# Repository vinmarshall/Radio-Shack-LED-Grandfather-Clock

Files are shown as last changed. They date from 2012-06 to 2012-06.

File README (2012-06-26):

These files are the plans for the "Radio Shack LED Grandfather Clock" project
that was featured in the July 2012 issue of Popular Science.  Look at
the instructions file for more information.

./grandfather_clock_code - Arduino code

./mechanical - CAD files and laser cutting templates.

./parts - Bill of Materials and parts sourcing information.

./PCB - Circuit schematic and board layout in the Express PCB format.

./schematic - The schematic for the circuit.

instructions.pdf - Instructions for building this project.

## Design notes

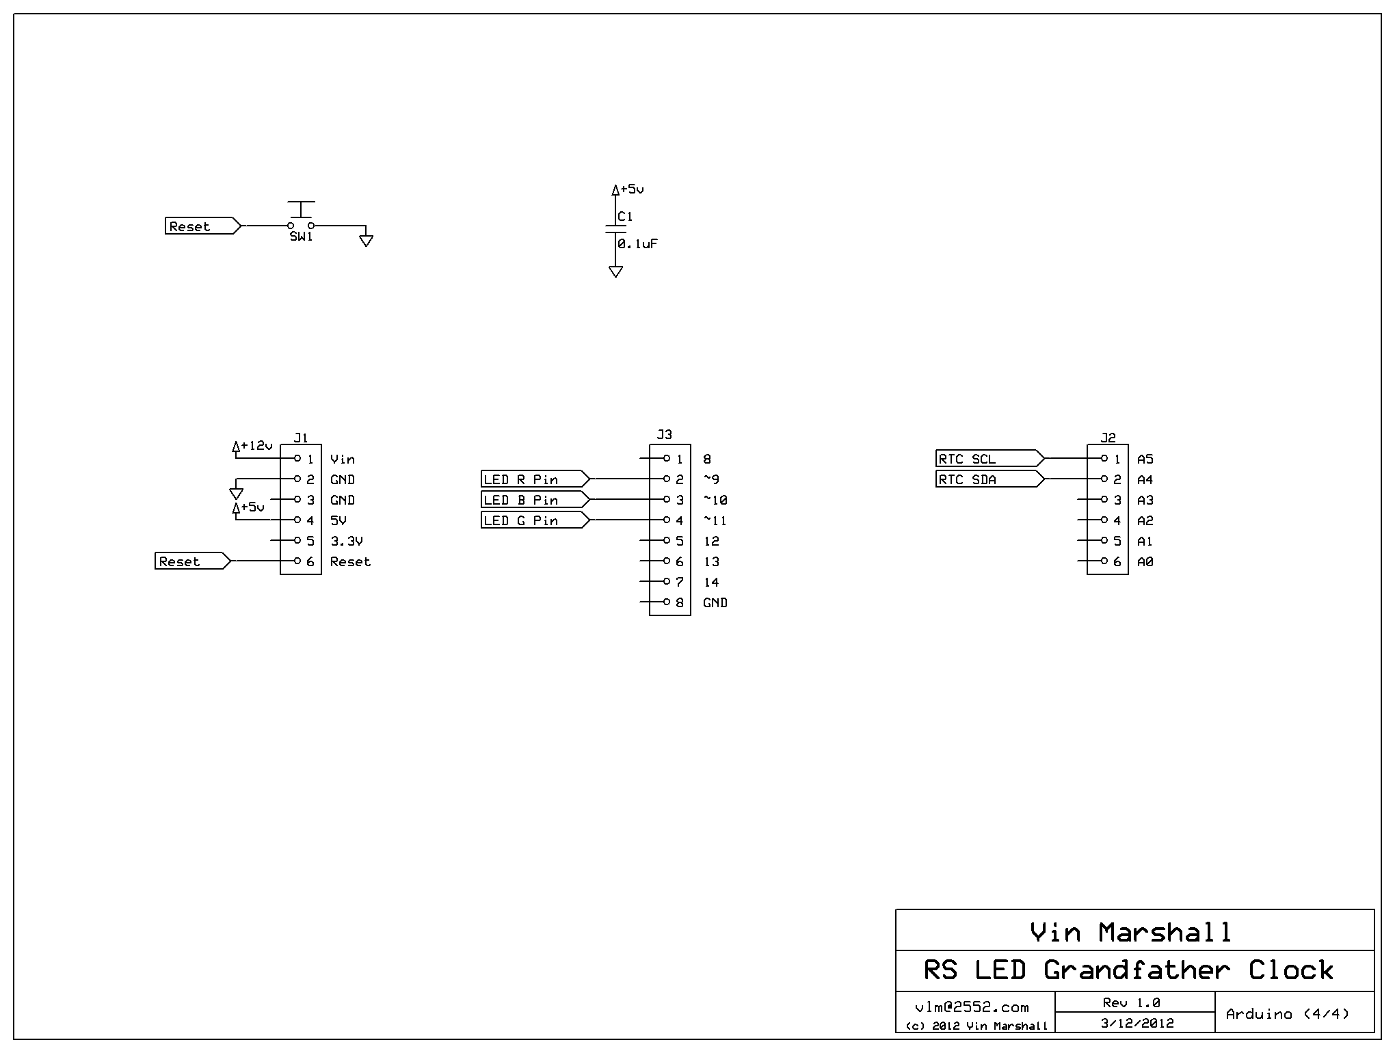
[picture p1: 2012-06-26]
schematic/4_Arduino.bmp

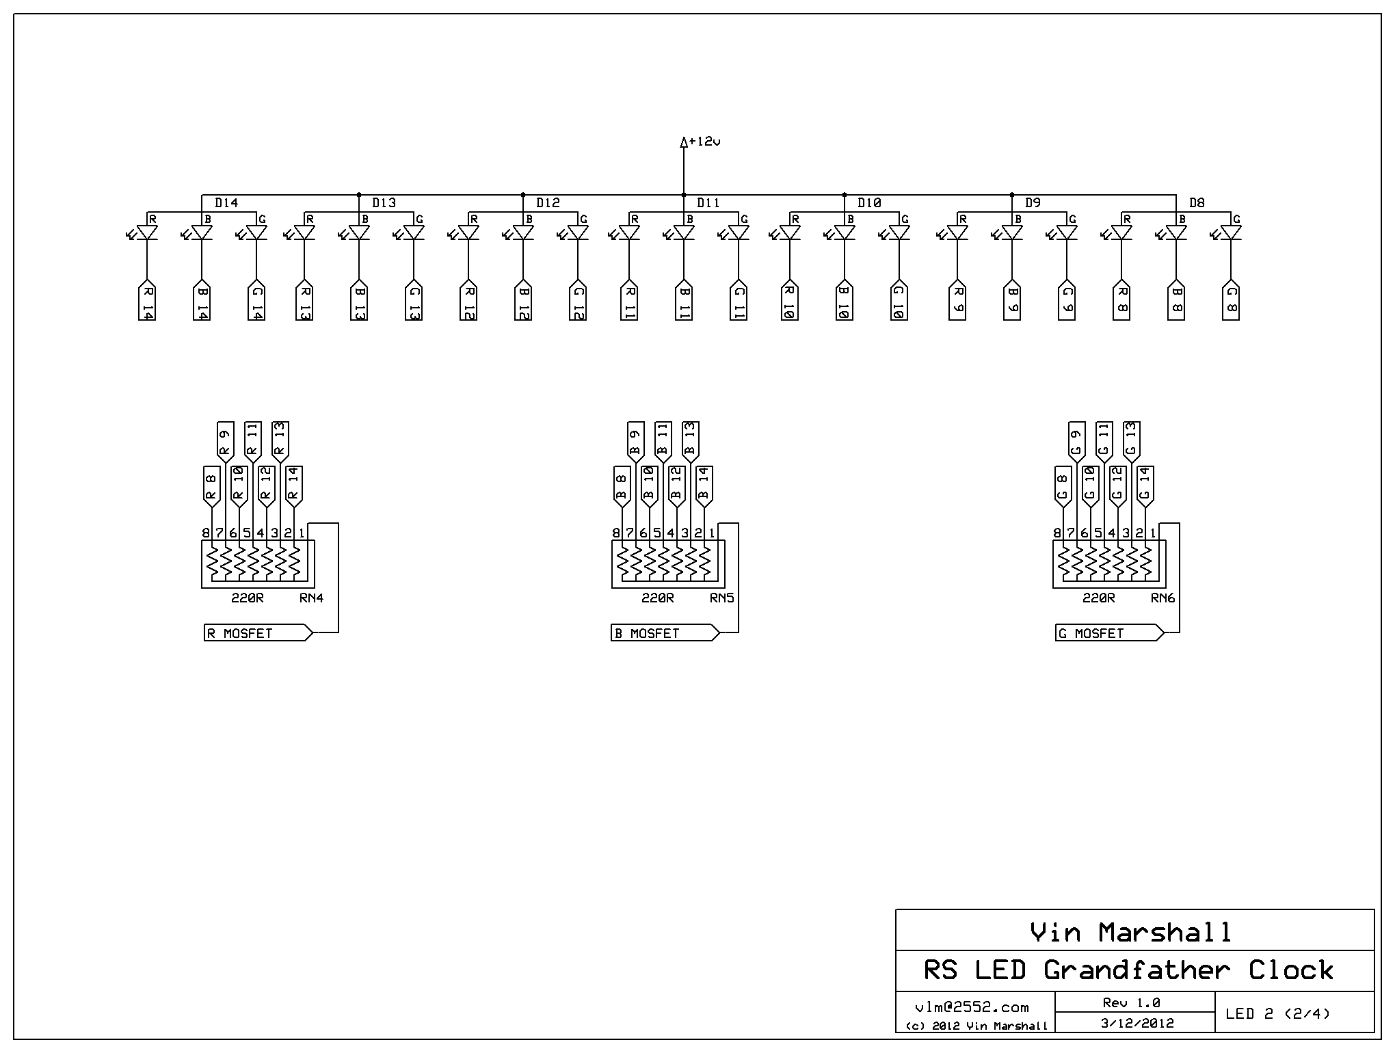
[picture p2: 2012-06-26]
schematic/2_LED2.bmp

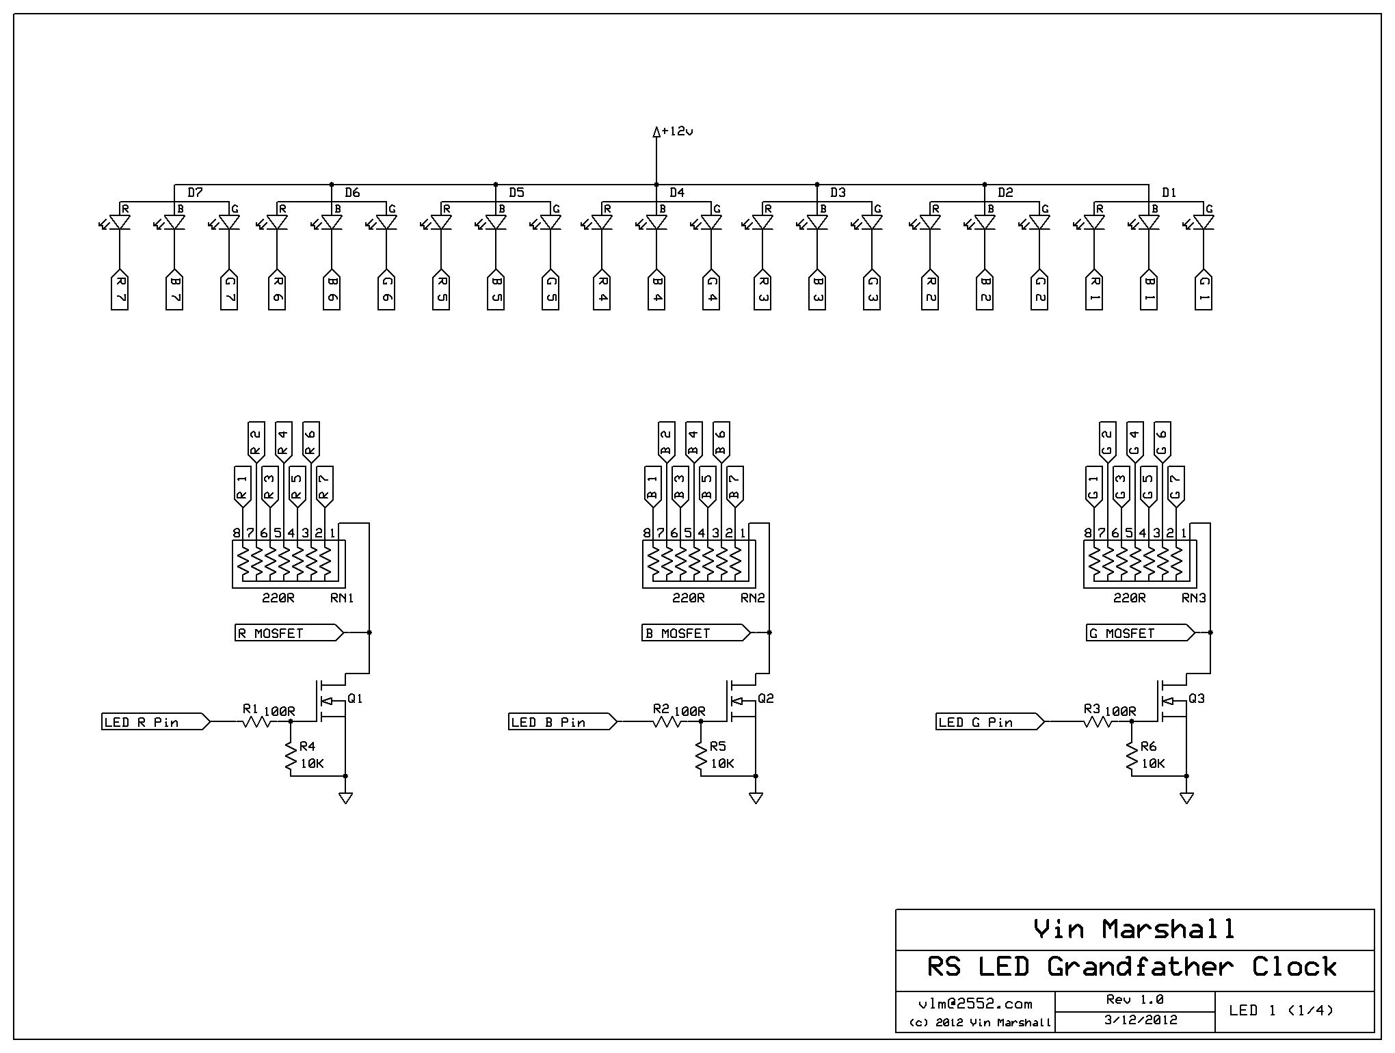
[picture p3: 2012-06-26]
schematic/1_LED1.bmp

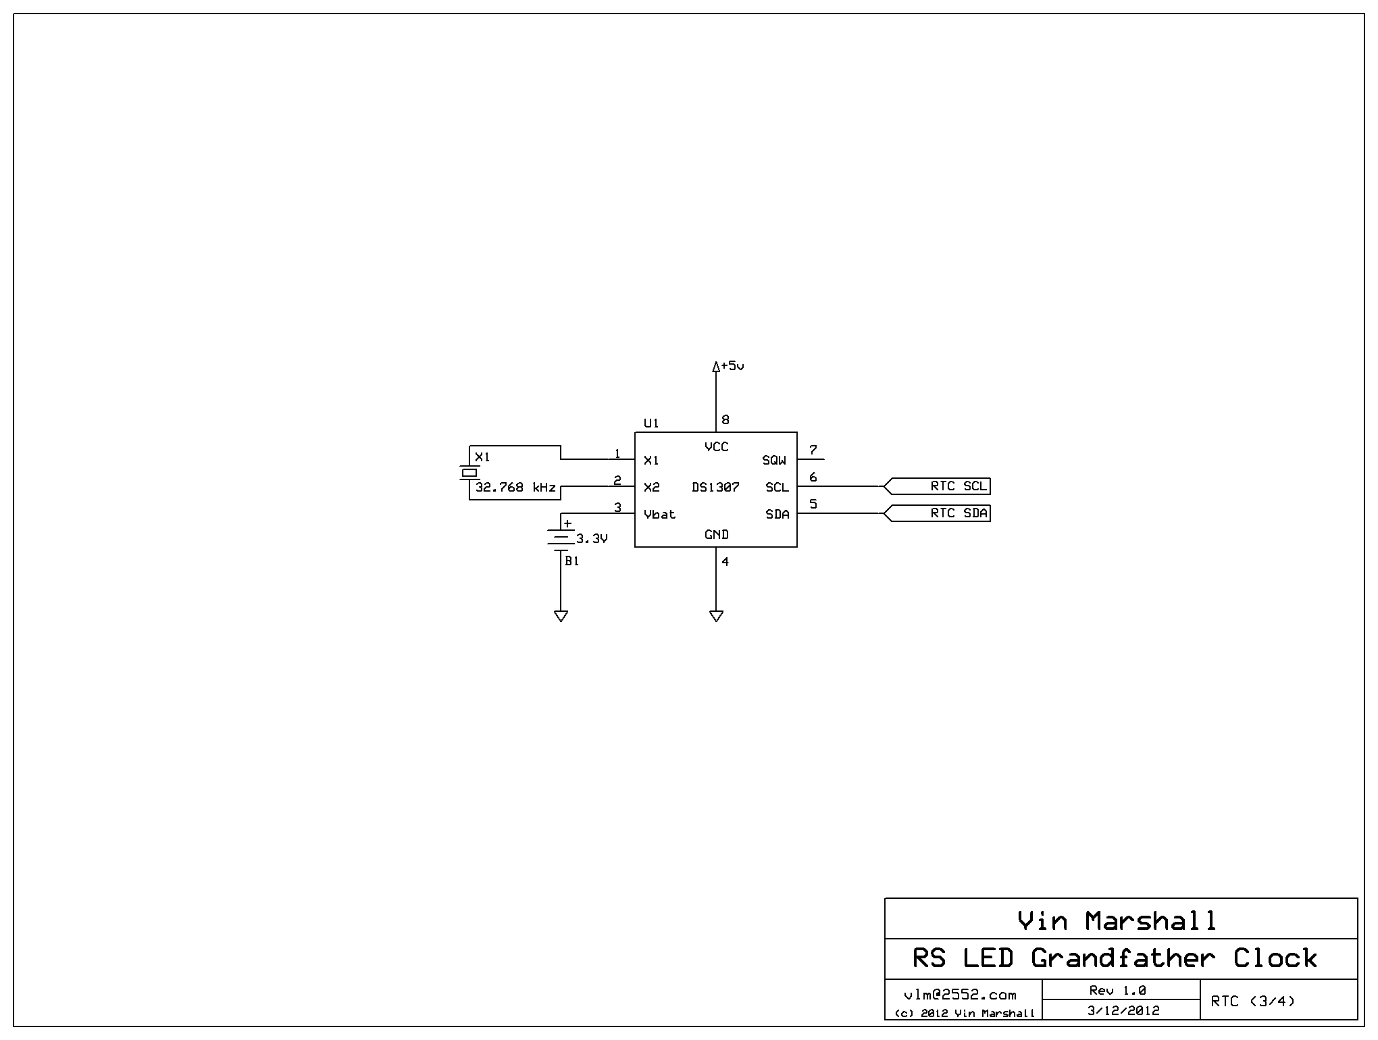
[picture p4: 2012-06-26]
schematic/3_RTC.bmp

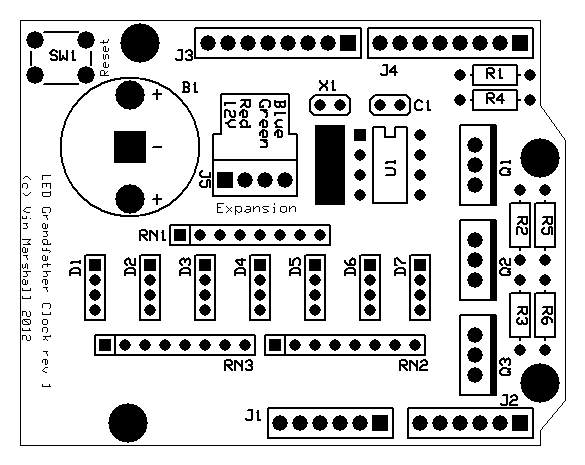
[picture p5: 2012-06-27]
PCB/led_grandfather_clock_shield.bmp

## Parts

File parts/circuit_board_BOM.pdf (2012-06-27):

### Sheet1

### Radio Shack LED Grandfather Clock – Circuit Board Bill Of Materials

Part | Type | Vendor and Part Number
B1 | 3.3V | RS 23-794
C1 | 0.1uF | DK 399-4264-ND
D1 | RGB LED | RS 276-0028
D2 | RGB LED | RS 276-0028
D3 | RGB LED | RS 276-0028
D4 | RGB LED | RS 276-0028
D5 | RGB LED | RS 276-0028
D6 | RGB LED | RS 276-0028
D7 | RGB LED | RS 276-0028
J1 | 0.1" Header Pins | DK SAM1035-50-ND
J2 | 0.1" Header Pins | DK SAM1035-50-ND
J3 | 0.1" Header Pins | DK SAM1035-50-ND
J5 | 4 Pin Right Angle 0.1” Header DK WM4302-ND
Q1 | IRF510 N-channel MOSFET | RS 276-2072
Q2 | IRF510 N-channel MOSFET | RS 276-2072
Q3 | IRF510 N-channel MOSFET | RS 276-2072
R1 | 100R | RS 271-1311
R2 | 100R | RS 271-1311
R3 | 100R | RS 271-1311
R4 | 10K | RS 271-1335
R5 | 10K | RS 271-1335
R6 | 10K | RS 271-1335
RN1 | 220R | DK 4608X-1-221LF-ND
RN2 | 220R | DK 4608X-1-221LF-ND
RN3 | 220R | DK 4608X-1-221LF-ND
SW1 | Reset Button | DK SW400-ND
U1 | DS1307 | DK DS1307+-ND
X1 | 32.768 kHz | DK X802-ND
| | RS = Radio Shack
| | DK = Digi-Key

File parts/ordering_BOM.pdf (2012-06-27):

Sheet1

### LED Grandfather Clock – Bill Of Materials

Version 1.0

Check for the most recent version of this file at:

Quantity | Part | Vendor | Part Number | Source
1 | | Radio Shack | 276-128
7 | RGB LED | Radio Shack | 276-028
3 | IRF-510 MOSFET N-Channel | Radio Shack | 276-2072
1 | 100 ohm 1/4W Resistors | Radio Shack | 271-1311
1 | 10K ohm 1/4W Resistors | Radio Shack | 271-1335
1 | 12V Power Supply | Radio Shack | 273-0357
1 | Size 'K' Power Supply Plug | Radio Shack | 273-0342
1 | CR1225 Coin Cell Battery | Radio Shack | 23-794
1 | Printed Circuit Board | Express PCB | N/A
| | Radio Shack | 276-0140
1 | | | SW400-ND
2 | 330 ohm Bussed Resistor Array | | 4608X-1-331LF-ND
1 | 220 ohm Bussed Resistor Array | | 4608X-1-221LF-ND
1 | 0.1” Header Pins | | SAM1035-50-ND
1 (optional) | 4 Pin Right Angle 0.1” Header | | WM4302-ND
1 | DS1307 RTC | | DS1307+-ND
1 | | | X802-ND
1 | 0.1uF Capacitor | | 399-4264-ND
1 | 12mm Coin Cell Battery Holder | | 3001K-ND
1 | Mirrored Plexiglass Reflector | | N/A
1 | White Plexiglass Diffuser | | N/A
1 | 4-40 x 7/16” L Nylon Standoffs | | 92745A472
1 | 4-40 x 3/4” L Nylon Standoffs | | 92745A324
1 | 4-40 x 1/2” SS Threaded Studs | | 95412A409
1 | 4-40 Nylon Nuts | | 94812A112

https://github.com/vinmarshall/Radio-Shack-LED-Grandfather-Clock

Arduino Uno Rev 3 | | www.radioshack.com
| | www.radioshack.com
| | www.radioshack.com
| | www.radioshack.com
| | www.radioshack.com
| | www.radioshack.com
| | www.radioshack.com
| | www.radioshack.com
| | www.expresspcb.com
OR Arduino Proto Shield | | www.radioshack.com
Pushbutton | DigiKey | www.digikey.com
| DigiKey | www.digikey.com
| DigiKey | www.digikey.com
| DigiKey | www.digikey.com
| DigiKey | www.digikey.com
| DigiKey | www.digikey.com
32.768 KHz Crystal | DigiKey | www.digikey.com
| DigiKey | www.digikey.com
| DigiKey | www.digikey.com
| Pololu | www.pololu.com
| Pololu | www.pololu.com
| McMaster Carr | www.mcmaster.com
| McMaster Carr | www.mcmaster.com
| McMaster Carr | www.mcmaster.com
| McMaster Carr | www.mcmaster.com

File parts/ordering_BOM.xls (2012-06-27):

LED Grandfather Clock – Bill Of Materials
Version 1.0
Check for the most recent version of this file at:
https://github.com/vinmarshall/Radio-Shack-LED-Grandfather-Clock
Quantity | Part | Vendor | Part Number | Source
1 | Arduino Uno Rev 3 | Radio Shack | 276-128 | www.radioshack.com
7 | RGB LED | Radio Shack | 276-028 | www.radioshack.com
3 | IRF-510 MOSFET N-Channel | Radio Shack | 276-2072 | www.radioshack.com
1 | 100 ohm 1/4W Resistors | Radio Shack | 271-1311 | www.radioshack.com
1 | 10K ohm 1/4W Resistors | Radio Shack | 271-1335 | www.radioshack.com
1 | 12V Power Supply | Radio Shack | 273-0357 | www.radioshack.com
1 | Size 'K' Power Supply Plug | Radio Shack | 273-0342 | www.radioshack.com
1 | CR1225 Coin Cell Battery | Radio Shack | 23-794 | www.radioshack.com
1 | Printed Circuit Board | Express PCB | N/A | www.expresspcb.com
 | OR Arduino Proto Shield | Radio Shack | 276-0140 | www.radioshack.com
1 | Pushbutton | DigiKey | SW400-ND | www.digikey.com
2 | 330 ohm Bussed Resistor Array | DigiKey | 4608X-1-331LF-ND | www.digikey.com
1 | 220 ohm Bussed Resistor Array | DigiKey | 4608X-1-221LF-ND | www.digikey.com
1 | 0.1” Header Pins | DigiKey | SAM1035-50-ND | www.digikey.com
1 (optional) | 4 Pin Right Angle 0.1” Header | DigiKey | WM4302-ND | www.digikey.com
1 | DS1307 RTC | DigiKey | DS1307+-ND | www.digikey.com
1 | 32.768 KHz Crystal | DigiKey | X802-ND | www.digikey.com
1 | 0.1uF Capacitor | DigiKey | 399-4264-ND | www.digikey.com
1 | 12mm Coin Cell Battery Holder | DigiKey | 3001K-ND | www.digikey.com
1 | Mirrored Plexiglass Reflector | Pololu | N/A | www.pololu.com
1 | White Plexiglass Diffuser | Pololu | N/A | www.pololu.com
1 | 4-40 x 7/16” L Nylon Standoffs | McMaster Carr | 92745A472 | www.mcmaster.com
1 | 4-40 x 3/4” L Nylon Standoffs | McMaster Carr | 92745A324 | www.mcmaster.com
1 | 4-40 x 1/2” SS Threaded Studs | McMaster Carr | 95412A409 | www.mcmaster.com
1 | 4-40 Nylon Nuts | McMaster Carr | 94812A112 | www.mcmaster.com

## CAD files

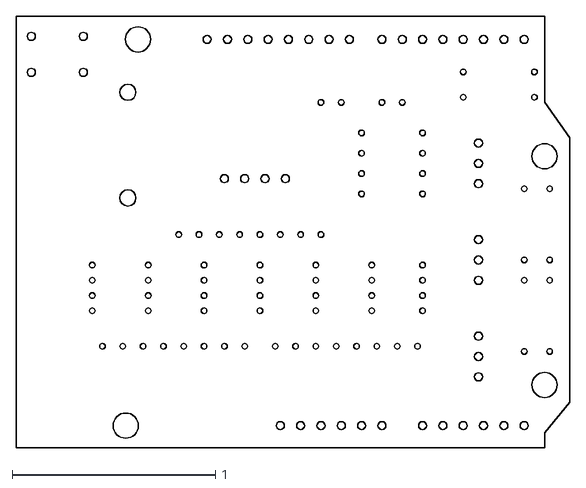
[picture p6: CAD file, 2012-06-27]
mechanical/led_grandfather_clock.dxf
2.73 x 2.12

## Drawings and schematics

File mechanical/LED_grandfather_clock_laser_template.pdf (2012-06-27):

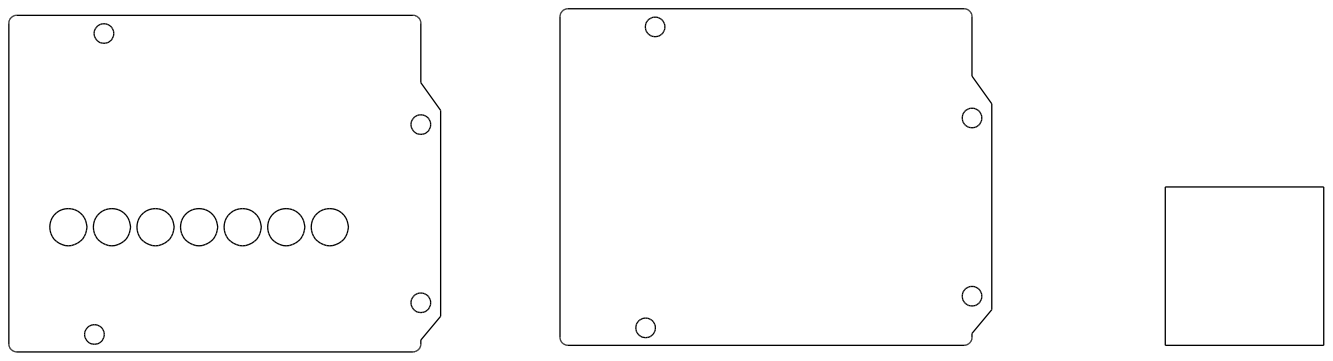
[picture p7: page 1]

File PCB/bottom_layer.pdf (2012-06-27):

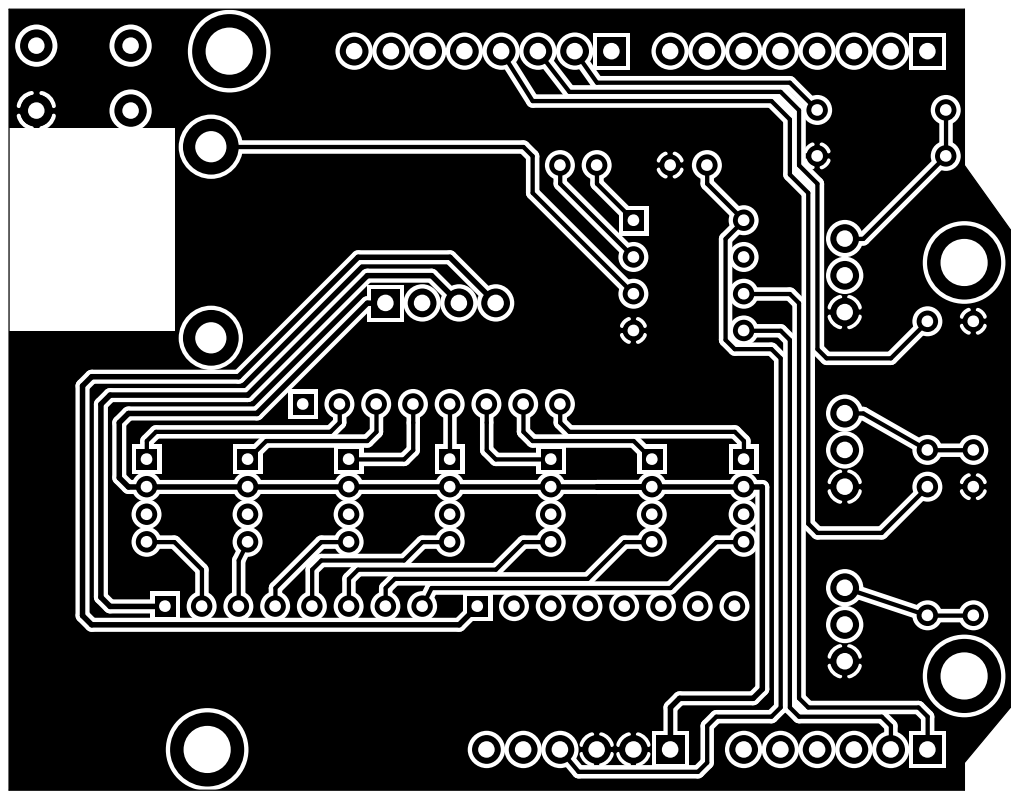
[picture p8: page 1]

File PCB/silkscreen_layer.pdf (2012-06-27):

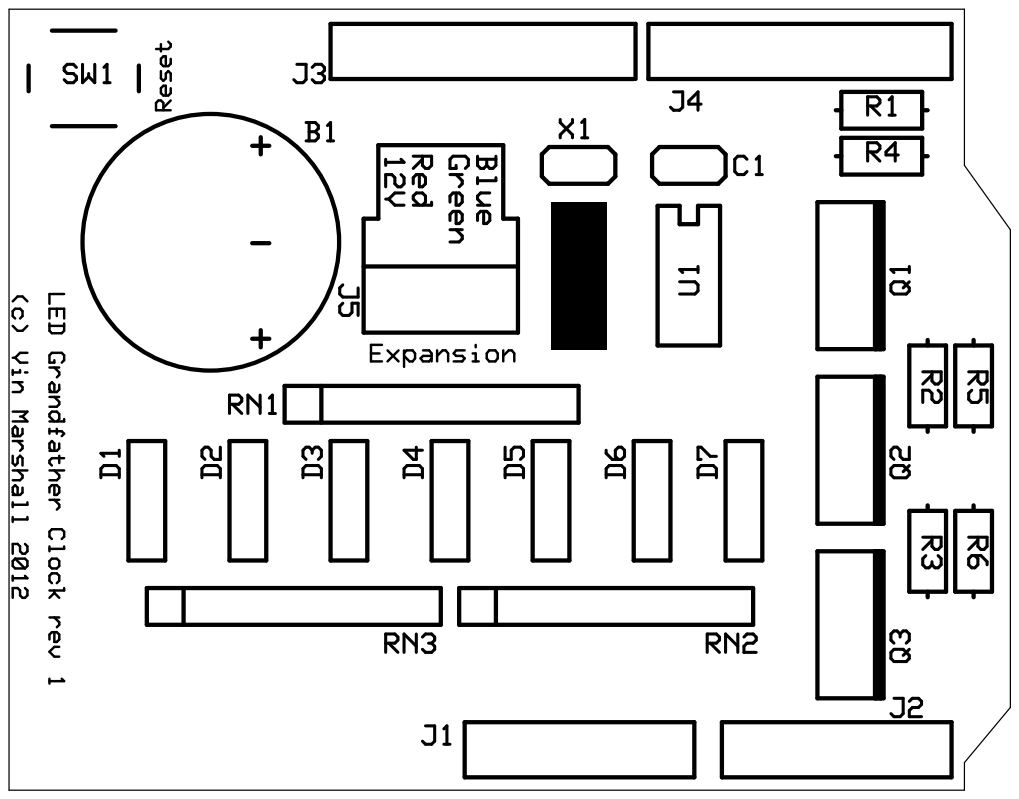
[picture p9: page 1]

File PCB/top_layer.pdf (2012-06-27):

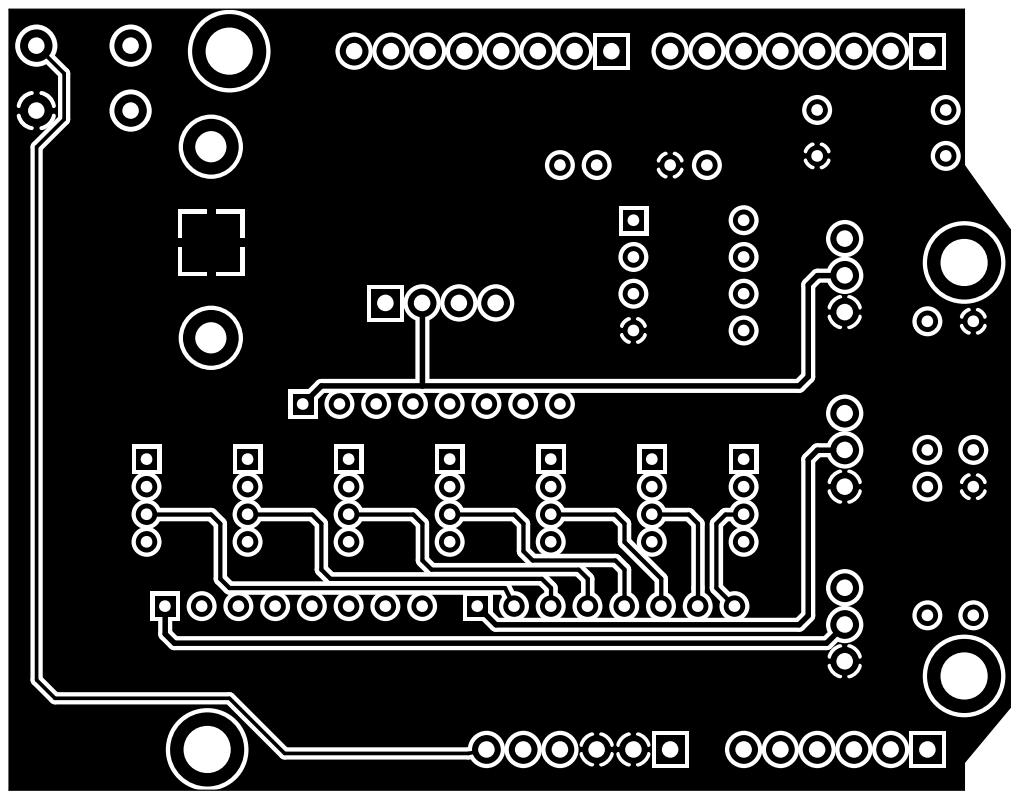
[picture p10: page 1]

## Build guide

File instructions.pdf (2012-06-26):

## LED Grandfather Clock

Version 1.0
Vin Marshall (vlm@2552.com) www.te-motorworks.com

Parts For This Project

Quantity | Part | Vendor | Part Number | Source
1 | Arduino Uno Rev 3 | Radio Shack | 276-128 | www.radioshack.com
7 | RGB LED | Radio Shack | 276-028 | www.radioshack.com
3 | IRF-510 MOSFET N-Channel | Radio Shack | 276-2072 | www.radioshack.com
1 | 100 ohm 1/4W Resistors | Radio Shack | 271-1311 | www.radioshack.com
1 | 10K ohm 1/4W Resistors | Radio Shack | 271-1335 | www.radioshack.com
1 | 9V Power Supply | Radio Shack | 273-0355 | www.radioshack.com
1 | Size 'K' Power Supply Plug | Radio Shack | 273-0342 | www.radioshack.com
1 | CR1225 Coin Cell Battery | Radio Shack | 23-794 | www.radioshack.com
1 | Printed Circuit Board | Express PCB | N/A | www.expresspcb.com
| OR Arduino Proto Shield | Radio Shack | 276-0140 | www.radioshack.com
1 | Pushbutton | DigiKey | SW400-ND | www.digikey.com
3 | 220 ohm Bussed Resistor Array | DigiKey | 4608X-1-221LF-ND | www.digikey.com
1 | 0.1” Header Pins | DigiKey | SAM1035-50-ND | www.digikey.com
1 | DS1307 RTC | DigiKey | DS1307+-ND | www.digikey.com
1 | 32.768 KHz Crystal | DigiKey | X802-ND | www.digikey.com
1 | 0.1uF Capacitor | DigiKey | 399-4264-ND | www.digikey.com
1 | 12mm Coin Cell Battery Holder | DigiKey | 3001K-ND | www.digikey.com
1 | Mirrored Acrylic Reflector | Pololu | N/A | www.pololu.com
1 | White Acrylic Diffuser | Pololu | N/A | www.pololu.com
1 | 4-40 x 1/2” L Nylon Pan Head Screws | McMaster Carr | 93135A110 | www.mcmaster.com
8 | 4-40 x 3/4” L Nylon Standoffs | McMaster Carr | 96110A012 | www.mcmaster.com
1 | 4-40 x 1/2” L SS Threaded Studs | McMaster Carr | 95412A409 | www.mcmaster.com
1 | 4-40 x 7/16” L Nylon Standoffs | McMaster Carr | 92745A472 | www.mcmaster.com
1 | 4-40 Nylon Nuts | McMaster Carr | 94812A112 | www.mcmaster.com
1 | Fillsta Table Lamp | Ikea | 501.550.18 | www.ikea.com

Assembly Instructions

Introduction:

There is a theme in many of my projects to display information in an approximate way. I'm often more interested in a sense of the data than the exact numbers. In this project, I applied that thinking to timekeeping and created a LED Grandfather Clock that strikes the passage of time while not actually telling you what time it is.
Please read the instructions all the way through before starting the project.
All of the supporting files for this project can be downloaded (use the ZIP button) from: https://github.com/vinmarshall/Radio-Shack-LED-Grandfather-Clock

Step 1: Program The Arduino

If you don't already have it, download the Arduino software from http://www.arduino.cc/.
Open the Arduino software and connect the Arduino to your computer via USB. Under the “Tools” drop down menu, select your board type (Arduino UNO for this project) and serial port (/dev/tty.usbmodem***).
The code for this project is in ./grandfather_clock_code directory in the download. Open it with the Arduino software and download the program to the Arduino.
If you have any problems with connecting and programming the Arduino, consult the help available in the Arduino forums at http://arduino.cc/forum/.
Once the Arduino has been successfully programmed, disconnect it from the computer and put it aside for now.
Check for the most recent version of the code here: https://github.com/vinmarshall/Radio-Shack-LED-Grandfather-Clock/blob/master/grandfather_clock_code/grandfather_clock_code.pde (https://github.com/vinmarshall/Radio-Shack-LED-Grandfather-Clock/blob/master/grandfather_clock_code/grandfather_clock_code.pde)

Step 2: Build The Circuit Board

The circuit board for this project gets built in two steps. All of the components except for the LEDs get assembled in this step.
First, cut the header pins that will plug into the Arduino:
- 2 x 6 pins for the Analog and Power side
- 2 x 8 pins for the Digital side

Next, press the long ends of the header pins into the female headers on the Arduino board. Two pins on each side of the Arduino's headers closest to the power jack and the USB jack will remain empty. Place the empty circuit board onto the protruding short end of the header pins. Verify that the mounting holes are properly aligned and solder all of the pins in place from the top of the board.
Remove the Arduino from the circuit board and place it aside after these pins are soldered in place.
Then install the remainder of the components – except for the LEDs – as per the led_grandfather_clock_shield.bmp drawing in the ./PCB directory and the circuit board BOM in the ./parts directory of the download. Your circuit board will look slightly different than what is pictured above.
Be careful when handling and installing the MOSFETS, as they are sensitive to ESD – static shocks. Touch something grounded before handling them. When installing the MOSFETS in the board, press them in as far as they will go – make sure they stick out a little bit less than 3/4” above the circuit board so that they will clear the next part to be mounted above.

Step 3: Install The LEDs

Each of the LEDs needs to align with the corresponding hole in the acrylic reflector. To ensure that, install the LEDs with the reflector temporarily in place.
Nylon standoffs get attached to the top and bottom of the circuit board. The 3/16” hex x 7/16” long nylon standoffs go on the bottom of the board – they will eventually attach to the Arduino. The threaded end should point away from the board. The 1/4” round x 3/4” long nylon standoffs go on the top of the board.
Install the 4-40 x 1/2” L stainless steel studs into one end of the 3/4” long standoffs and attach the two sets of standoffs to the board as pictured above. Your board will look slightly different than the picture. Only tighten these hand tight.
Temporarily attach the mirrored acrylic reflector onto the top of the 3/4” standoffs with the 4-40 pan head screws.
To install the LEDs, first gently spread each of the pins slightly. The holes in the PCB are on a 0.1” spacing – the same as a prototyping breadboard. Then press an LED through a hole in the reflector and line the pins up with the corresponding holes in the circuit board. The longest pin of the LED goes in the hole next to the one with the square pad. Getting all of the pins to fit will probably require prodding from tweezers or a small screwdriver. Push each LED in until the base of the LED lens is about halfway through the reflector. The reflector should hold the LEDs in place as your solder the pins.
Working one at a time, install and solder each of the LEDs in this manner. Start with the position nearest the MOSFETs.

Step 4: Attach The Arduino

The Arduino, already programmed, is ready to go. Press the circuit board onto the Arduino ensuring that all pins line up correctly. The nylon standoffs may take a bit of wrestling – particularly the one nearest the USB jack. Rotate that standoff so that a flat is aligned with the plastic header next to it.
Once the Arduino and the circuit board are mated, spin the nylon nuts onto the bottom of the standoffs. Only tighten them hand tight.
At this point, we can power up and test the circuit. First, install the K size plug onto the 9V power supply so that the tip is positive. Then power up the Arduino. If you don't see light at first, try pressing the reset button.
If you still don't see light, double check that the Arduino was successfully programmed and double check your wiring.

Step 5: Install The Reflector and Diffuser

The acrylic reflector and diffusion elements help the LEDs to be a lot more effective. These parts can both be sourced from Pololu.com's laser cutting service. Order using the led_grandfather_clock_laser_template.dxf file in the ./mechanical directory.
To install these parts, first remove the pan head screws holding the reflector in place. Replace them with another set of 4-40 x 1/2” studs. Screw another set of 3/4” nylon spacers onto those studs, again tightening only hand tight. Place the translucent white plastic diffusion element on top of those standoffs and attach it with the pan head screws that were holding the reflector in place.

Step 6: Build The Lamp

Follow the Swedish pictograms to assemble the Ikean lamp.

Step 7: Put It All Together

At this point, the lamp is assembled and the circuit is built. Route the power cord up through the base of the lamp, plug it into the circuit, and drop it into place.
When daylight savings comes around, just turn off the power, pull out the circuit, and reprogram the Arduino. The time on the clock will automatically be updated to the time on your computer.
The circuit will keep time even when it is not plugged in. The coin cell battery will keep the clock going for about 10 years without external power.

Check for the latest version of this document at: https://github.com/vinmarshall/Radio-Shack-LED-Grandfather-Clock

Copyright 2012 Vin Marshall (vlm@2552.com)
DISCLAIMER: This project is not a consumer product; it is just one hobbyist sharing his plans. It is provided "AS IS" without warranty of any kind, either expressed or implied, including, but not limited to the implied warranties of merchantability and fitness for a particular purpose. You are building and operating this at your own risk.

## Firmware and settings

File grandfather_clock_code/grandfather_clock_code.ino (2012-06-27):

/* LED Grandfather Clock v1.0
 *
 * A Grandfather Clock that chimes the quarter, half, and full hours
 * by way of RGB LEDs.  There is no external time display other than 
 * these periodic chimes - it communicates the passing of time, not 
 * the time itself.  One chime for the quarter hour, two for the half
 * hour, and the number of the hour at the top of the hour.
 *
 * This code is for the Radio Shack LED Grandfather Clock project in the
 * July 2012 issue of PopSci.  
 *
 * Please check GitHub for the most recent version of this code.  The
 * code and other project files live on GitHub at:
 * https://github.com/vinmarshall/Radio-Shack-LED-Grandfather-Clock
 * 
 * Copyright (c) 2012 Vin Marshall (vlm@2552.com, www.2552.com)
 *
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
 */

#include <Time.h>  
#include <Wire.h>  
#include <DS1307RTC.h> 

#define RED_PIN 9
#define GREEN_PIN 11
#define BLUE_PIN 10
#define FADE_STEP 1.2
#define FADE_TIME_MS 50
#define CHIME_PAUSE_MS 1000

// Comment out if you don't want output to the serial console
#define DEBUG 1

// IMPORTANT:  Uncomment this for the first time you program the clock. 
// Then comment it out and reprogram the Arduino.  Leave it commented out 
// thereafer.  This enables setting the RTC to the time and date when this
// code was compiled - you only want it to do that the first time it starts.
//#define FIRST_RUN

struct RGB { 
  byte red;
  byte green;
  byte blue;
};

/*
 * Set these AM and PM color ratios to get the colors you want.  
 * Values for each color can be anything from 0 to 255 but it works
 * best to keep these values relatively small so that the "chime" will
 * be noticably brighter than the normal glow.
 */
RGB am_color = {12, 2, 7};
RGB pm_color = {2, 12, 7};
RGB error = {1, 0, 0};      // red
RGB ok = {0, 1, 0};         // green

void setup() {     
#ifdef DEBUG
  Serial.begin(9600);  
#endif
  
  // Ensure we can talk to the RTC and it has a time.
  setSyncProvider(RTC.get);
  if(timeStatus()!= timeSet) {
#ifdef DEBUG
    Serial.println("Unable to sync with the RTC");
#endif
    chime(error, 10);
  } else {
#ifdef DEBUG
    Serial.println("RTC has set the system time");
#endif
    chime(ok, 1);
  }
  
#ifdef FIRST_RUN
  // Sets the clock based on this code's compile time.  Make
  // sure the compiling computer's clock is set correctly.  
  setTimeByCompileTime();
#endif
  
  // TESTING
  // Just before the 10 AM hour chime
  //setTime(9, 59, 45, 1, 1, 2012); 
  // Just before the 4 PM hour chime
  //setTime(15, 59, 45, 1, 1, 2012);
  // Just before a quarter hour chime
  //setTime(0, 14, 45, 1, 1, 2012);
  // Just before a half hour chime
  //setTime(0, 29, 45, 1, 1, 2012);
  // Just before an AM to PM transition
  //setTime(11, 59, 45, 1, 1, 2012);
  
  // initialize the digital pin as an output.
  pinMode(RED_PIN, OUTPUT);     
  pinMode(GREEN_PIN, OUTPUT);
  pinMode(BLUE_PIN, OUTPUT);
}

RGB current_color;
int last_minute;
char buf[255];

void loop() {
  
  time_t time = now();
  
  // Choose the glow color by AM/PM
  if (isAM(time)) { current_color = am_color; }
  else { current_color = pm_color; }
  setLEDs(current_color);
  
  // Chime on quarter, half, and full hours
  // Check every time through the loop for a new minute
  if (minute(time) != last_minute) {
 
#ifdef DEBUG
    // Print time to serial console
    sprintf(buf, "%0.2d:%0.2d:%0.2d %d %s %d", \ 
            hour(time), minute(time), second(time), \
            day(time), monthShortStr(month(time)), year(time));
    Serial.println(buf);
#endif
    
    if (minute(time) == 0) { chime(current_color, hourFormat12(time)); }
    else if (minute(time) == 30) { chime(current_color, 2); }
    else if (minute(time) % 15 == 0) { chime(current_color, 1); }
  }

  // Take a rest.  This clock is not a study in punctuality.
  last_minute = minute(time);
  delay(500);
}

/*
 * chime
 * Fades an RGB LED up and down keeping the color mix ratio
 * consistent.  
 * color: RGB struct with red, green, and blue 0-255 starting color values
 * num: number of times to cycle the fade up and down
 *
 * Expects FADE_STEP to be defined
 */
void chime(struct RGB color, int num) {
  unsigned int init_red = color.red;
  unsigned int init_green = color.green;
  unsigned int init_blue = color.blue;
  
  // Fade up and down 'num' times
  for (int i=0; i < num; i++) {
    
    // start at the initial color mix ratio
    unsigned int red = init_red;
    unsigned int green = init_green;
    unsigned int blue = init_blue;
    
    // Fade up, keeping the ratio intact.  Step when the 
    // brightest color component reaches full power.
    while (red < 255 && green < 255 && blue < 255) {
      red = ceil(red * FADE_STEP);
      green = ceil(green * FADE_STEP);
      blue = ceil(blue * FADE_STEP);
      
      // and adjust the LEDs to the current values
      setLEDs(red, green, blue);
      delay(FADE_TIME_MS);
    }
    
    // Pause to accentuate the chime
    delay(CHIME_PAUSE_MS);
    
    // Fade down, keeping the ratio intact.  Step when the 
    // brightest color component reaches the original power level.
    while (red > init_red && green > init_green && blue > init_blue) {
      red /= FADE_STEP;
      green /= FADE_STEP;
      blue /= FADE_STEP;
      
      // and adjust the LEDs to the current values
      setLEDs(red, green, blue);
      delay(FADE_TIME_MS);
    }
    
    // Pause to accentuate the chime
    delay(CHIME_PAUSE_MS);
  }
}

/*
 * setLEDs
 *
 * Expects RED_PIN, GREEN_PIN, and BLUE_PIN to be defined and
 * configured as output pins.  
 */
void setLEDs(int red, int green, int blue) {
  analogWrite(RED_PIN, limitTo(red, 0, 255));
  analogWrite(GREEN_PIN, limitTo(green, 0, 255));
  analogWrite(BLUE_PIN, limitTo(blue, 0, 255));
}

void setLEDs(struct RGB color) {
  setLEDs(color.red, color.green, color.blue);
}

/*
 * limitTo
 * Limits the supplied val to be within min and max.  Returns 
 * the constrained value.
 */
int limitTo(int val, int min, int max) {
  if (val < min) { val = min; }
  else if (val > max) { val = max; }
  return val;
}
  
/*
 * setTimeByCompileTime
 * Sets the connected RTC based on the time and date at which this program
 * was compiled, which is a reasonably accurate way to grab the time.  
 * That clever trick is courtesy of Adafruit:
 * http://www.ladyada.net/learn/breakoutplus/ds1307rtc.html
 */
void setTimeByCompileTime() {
  
  int hh, mm, ss;
  int MM, DD, YYYY;
  char MM_name[4];
  
  // Split the time and date
  // __TIME__ format: hh:mm:ss
  // __DATE__ format: Mon DD YYYY 
  sscanf(__TIME__, "%d:%d:%d", &hh, &mm, &ss);
  sscanf(__DATE__, "%s %d %d", &MM_name, &DD, &YYYY);

  // find month number for the UTC month short name
  for (MM = 0; MM < 13; MM++) {
    if (strcmp(monthShortStr(MM), MM_name) == 0)
      break;
  }
  
  // And set the clock to the parsed compile time and date
  setTime(hh, mm, ss, DD, MM, YYYY);
  time_t set = now();
  RTC.set(set);
}

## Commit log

2012-03-08 Imported PCB and mechanical drawings
    [led_grandfather_clock_laser_template.dxf, rgb_led_shield.dxf, rgb_led_shield.sch]
2012-03-13 fixed second ground pin on mosfets
2012-06-26 arduino code v1.0
2012-06-26 cleaned up schematic
    [rgb_led_shield.sch]
2012-06-26 updated part numbers
    [rgb_led_shield.sch]
2012-06-26 updated part numbers in schematic
    [rgb_led_shield.sch]
2012-06-26 updated circuit board BOM
    [circuit_board_BOM.xls]
2012-06-26 updated ordering BOM
    [ordering_BOM.xls]
2012-06-26 filter cap
    [circuit_board_BOM.xls, rgb_led_shield.sch]
2012-06-26 schematic updates
    [rgb_led_shield.sch]
2012-06-26 renamed sch and pcb files
    [led_grandfather_clock.sch]
2012-06-26 updated rtc component # on schematic
    [led_grandfather_clock.sch]
2012-06-27 revised PCB layout
    [led_grandfather_clock.dxf, led_grandfather_clock.sch]
2012-06-27 updated expansion header part number
    [circuit_board_BOM.xls, led_grandfather_clock.sch, ordering_BOM.xls]
2012-06-27 updated the plastic reflectors and diffuser for new LED layout
    [led_grandfather_clock_laser_template.dxf, rgb_led_shield.dxf]
